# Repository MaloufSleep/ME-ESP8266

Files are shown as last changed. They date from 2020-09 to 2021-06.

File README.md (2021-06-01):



# ME-ESP8266
Malouf Electronics - ESP8266 Dev Board

The ultimate ESP8266 development board built by makers for makers.



[Malouf Electronics website](https://www.maloufelectronics.com)



## SPECIFICATIONS / FEATURES



* 16 MB Flash
* 5V Relay
* RS232 interface
* IR Receiver
* IR LED
* Terminal Block for Power & RS232
* Terminal Block for Relay
* Easily accessible GPIO
* Micro USB (power & programming)

## GETTING STARTED
1. Download Arduino IDE (https://www.arduino.cc/en/Main/Software)
2. Setup ESP8266 support for Arduino IDE:
* Start Arduino and open Preferences window.
* Enter https://arduino.esp8266.com/stable/package_esp8266com_index.json into the Additional Board Manager URLs field.
* Open Boards Manager from the Tools > Board menu and find esp8266 platform.
* Select the version you need from the drop-down box.
* Click the Install button.
* Don't forget to select your ESP8266 board from the Tools > Board menu after installation.
3. Select "Generic ESP8266 Module"
4. Pick the following from the Tools menu:
* Upload Speed: 115200
* CPU Frequency: 80MHz
* Crystal Frequency: 26MHz
* Flash Size: 16MB
* Flash Mode: DOUT
* Flash Frequency: 40MHz
* Port: (the serial port of your USB cable)
5. Paste the code below into a new sketch and upload to the board (In order to upload you may have to hold the boot button until esptool connects):

```
const int LED_RED = 5;

void setup() {
    pinMode(LED_RED, OUTPUT);     // setup red LED as output
}

void loop() {

    digitalWrite(LED_RED, LOW);   // turn the LED on
    delay(1000);                  // wait for a second

    digitalWrite(LED_RED, HIGH);  // turn the LED off
    delay(1000);                  // wait for a second

}
```

If all goes well the board will program and the red LED will start blinking.



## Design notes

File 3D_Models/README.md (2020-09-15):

The folders here contain 3d models of any ‘non-standard’ part, meaning the kicad libraries don’t contain them. Folders are named to match kicad’s naming convention so you can merge them with the global folders if you’d like (/Library/Application Support/kicad/modules/packages3d). This will allow you to use the same models between projects without having to change file paths. 

If you need/want any other 3d models for the project, please let me know and I’ll get them to you.

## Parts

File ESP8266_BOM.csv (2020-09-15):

Designator | Quantity | Value | LCSC Part # | Footprint | Notes
C1, | 1 | TAJB107K006RNJ | C16133 | Capacitor_Tantalum_SMD:CP_EIA-3528-15_AVX-H
C3, C16, C17, | 3 | CL21A106KAYNNNE | C15850 | Capacitor_SMD:C_0805_2012Metric
C4, C5, C13, C14, C15, C12, | 6 | CL10A105KB8NNNC | C15849 | Capacitor_SMD:C_0603_1608Metric
C6, | 1 | 0402CG2R7C500NT | C1561 | Capacitor_SMD:C_0402_1005Metric
C7, | 1 | 0603CG3R0C500NT | C46219 | Capacitor_SMD:C_0603_1608Metric
C8, C2, C11, C18, C19, | 5 | CC0603KRX7R9BB104 | C14663 | Capacitor_SMD:C_0603_1608Metric
C9, C10, | 2 | 0603CG6R8C500NT | C1679 | Capacitor_SMD:C_0603_1608Metric
D4, | 1 | SS14 | C2480 | Diode_SMD:DO-214AC
D5, | 1 | M7 | C95872 | Diode_SMD:DO-214AC
L1, | 1 | SDCL1005C4N3STDF | C52051 | Inductor_SMD:L_0402_1005Metric
L2, | 1 | LQG15HS2N2S02D | C86061 | Inductor_SMD:L_0402_1005Metric
Q2, Q3, Q6, Q1, | 4 | AO3400A | C20917 | Package_TO_SOT_SMD:SOT-23
Q4, Q5, | 2 | S8050_SMD | C2146 | Package_TO_SOT_SMD:SOT-23
R1, | 1 | 0603WAF2000T5E | C8218 | Resistor_SMD:R_0603_1608Metric
R2, R4, R5, R6, R7, R12, R13, R24, R25, R26, R20, | 11 | 0603WAF1002T5E | C25804 | Resistor_SMD:R_0603_1608Metric
R3, | 1 | 0603WAF1202T5E | C22790 | Resistor_SMD:R_0603_1608Metric
R8, R14, R23, R22, R21, R19, R15, R16, | 8 | 0603WAF4700T5E | C23179 | Resistor_SMD:R_0603_1608Metric
R9, R11, R10, | 3 | 0603WAF620JT5E | C23222 | Resistor_SMD:R_0603_1608Metric
R17, | 1 | 0805W8F2203T5E | C17556 | Resistor_SMD:R_0805_2012Metric
R18, | 1 | 0805W8F8202T5E | C17840 | Resistor_SMD:R_0805_2012Metric
SW1, SW2, | 2 | TS-1187A-B-A-B | C318884 | Button_Switch_SMD:TS-1187A-B-A-B
U1, | 1 | W25Q128JVSIQ | C97521 | Package_SO:SO-8_5.3x6.2mm_P1.27mm
U2, | 1 | ESP8266EX | C77967 | Package_DFN_QFN:QFN-32-1EP_5x5mm_P0.5mm_EP3.45x3.45mm_ThermalVias
U3, | 1 | MAX232ESE+T | C26860 | Package_SO:SOIC-16_3.9x9.9mm_P1.27mm
U4, | 1 | NCP1117-3.3_SOT223 | C26537 | Package_TO_SOT_SMD:SOT-223-3_TabPin2
U5, | 1 | CH340C | C84681 | Package_SO:SOIC-16_3.9x9.9mm_P1.27mm
X1, | 1 | X1E000021081900 | C91747 | Crystal:Crystal_SMD_3225-4Pin_3.2x2.5mm
D1 | 1 | QBL7SA60D |  | LED_3mm_Radial | substitution okay
D2 | 1 | QBL7IG60D |  | LED_3mm_Radial | substitution okay
D3 | 1 | TSHA4400 |  | LED_3mm_Radial | substitution okay
J1, | 1 | 282834-4 |  | TerminalBlock_TE-Connectivity:TerminalBlock_TE_282834-4_1x04_P2.54mm_Horizontal | substitution okay
J2, | 1 | 68000-113HLF |  | Connector_PinHeader_2.54mm:PinHeader_1x13_P2.54mm_Vertical | substitution okay
J3, | 1 | 10118193-0001LF |  | digikey-footprints:USB_Micro_B_Female_10118193-0001LF | substitution okay
J4, | 1 | 68000-102HLF |  | Connector_PinHeader_2.54mm:PinHeader_1x02_P2.54mm_Vertical | substitution okay
J5, | 1 | 284391-3 |  | TerminalBlock_TE-Connectivity:TE_284391-3 | substitution okay
K1, | 1 | G5LE-14 DC5 |  | Relay_THT:Relay_SPDT_Omron-G5LE-1 | substitution okay
U6, | 1 | VS1838B |  | OptoDevice:Vishay_MOLD-3Pin | substitution okay

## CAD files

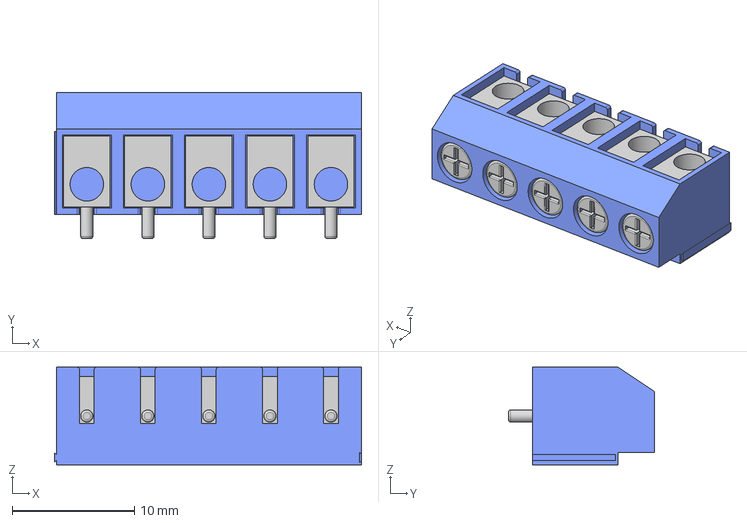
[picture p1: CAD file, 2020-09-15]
3D_Models/screw-terminal-block-5mm-2.snapshot.17/Screw Terminal Block 5mm Blue 5-way.step
25.1 x 12.0 x 8.00 mm

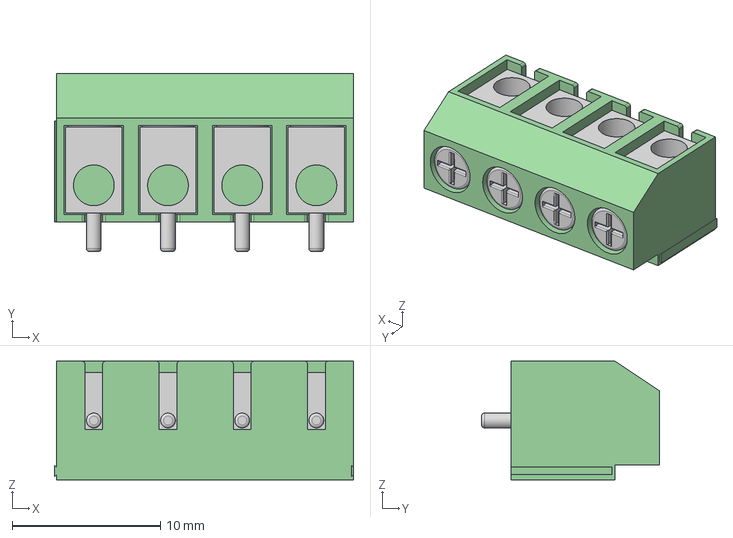
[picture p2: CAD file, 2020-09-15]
3D_Models/screw-terminal-block-5mm-2.snapshot.17/Screw Terminal Block 5mm 4-way.step
20.1 x 12.0 x 8.00 mm

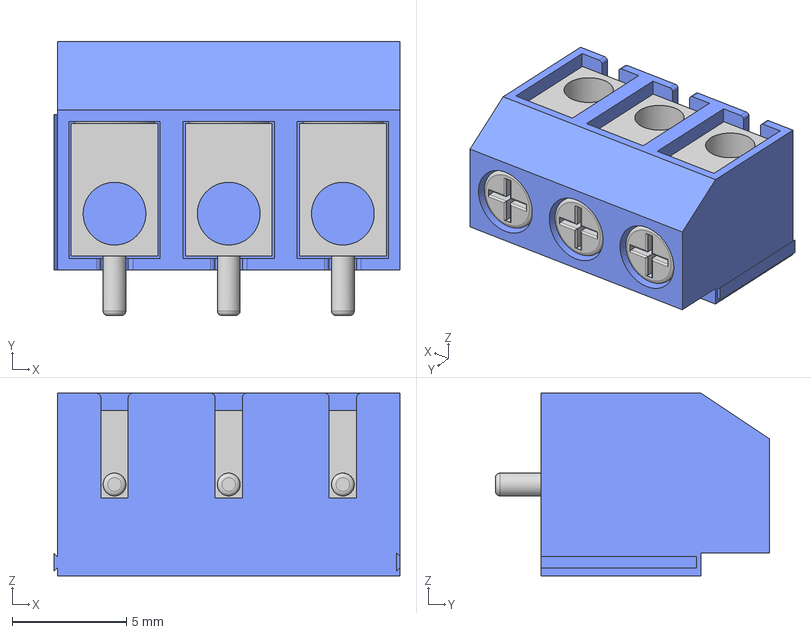
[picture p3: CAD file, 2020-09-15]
3D_Models/screw-terminal-block-5mm-2.snapshot.17/Screw Terminal Block 5mm Blue 3-way.step
15.2 x 12.0 x 8.00 mm

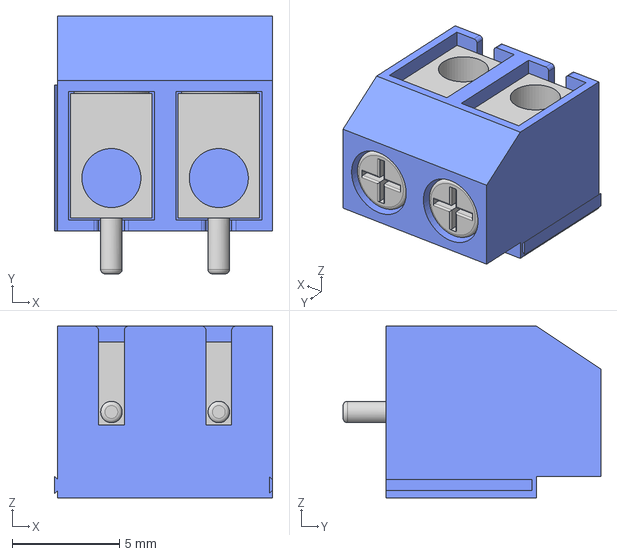
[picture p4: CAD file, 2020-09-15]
3D_Models/screw-terminal-block-5mm-2.snapshot.17/Screw Terminal Block 5mm Blue 2-way.step
10.2 x 12.0 x 8.00 mm

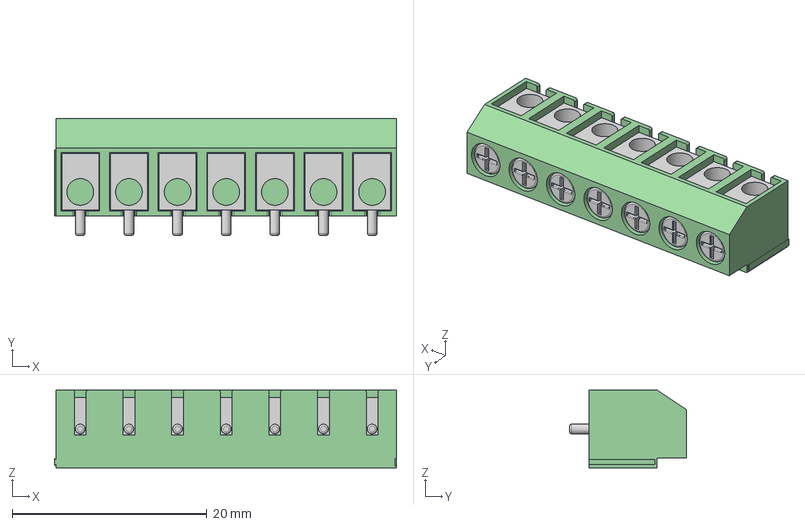
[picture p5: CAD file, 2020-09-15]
3D_Models/screw-terminal-block-5mm-2.snapshot.17/Screw Terminal Block 5mm 7-way.step
35.1 x 12.0 x 8.00 mm

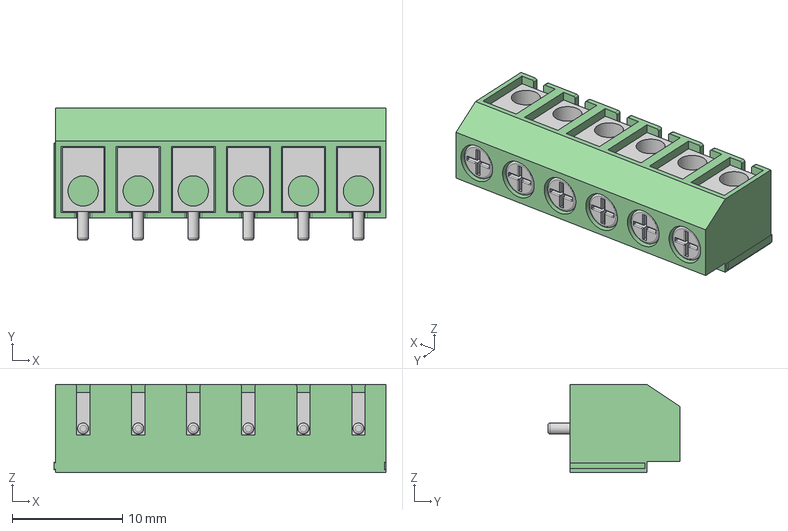
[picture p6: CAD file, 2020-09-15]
3D_Models/screw-terminal-block-5mm-2.snapshot.17/Screw Terminal Block 5mm 6-way.step
30.1 x 12.0 x 8.00 mm

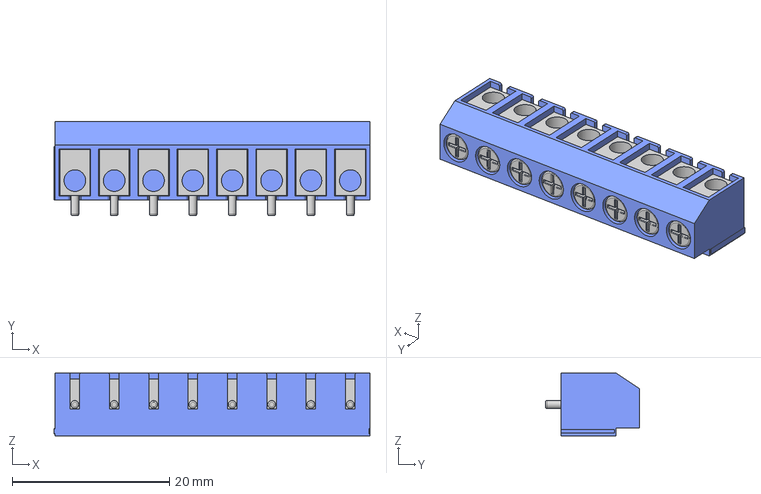
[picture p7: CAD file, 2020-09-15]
3D_Models/screw-terminal-block-5mm-2.snapshot.17/Screw Terminal Block 5mm Blue 8-way.step
40.1 x 12.0 x 8.00 mm

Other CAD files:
3D_Models/screw-terminal-block-5mm-2.snapshot.17/Screw Terminal Block 5mm Blue 7-way.step
3D_Models/screw-terminal-block-5mm-2.snapshot.17/Screw Terminal Block 5mm 8-way.step
3D_Models/screw-terminal-block-5mm-2.snapshot.17/Screw Terminal Block 5mm 5-way.step
3D_Models/screw-terminal-block-5mm-2.snapshot.17/Screw Terminal Block 5mm 2-way.step
3D_Models/screw-terminal-block-5mm-2.snapshot.17/Screw Terminal Block 5mm Blue 4-way.step
3D_Models/screw-terminal-block-5mm-2.snapshot.17/Screw Terminal Block 5mm Blue 6-way.step
3D_Models/screw-terminal-block-5mm-2.snapshot.17/Screw Terminal Block 5mm 3-way.step

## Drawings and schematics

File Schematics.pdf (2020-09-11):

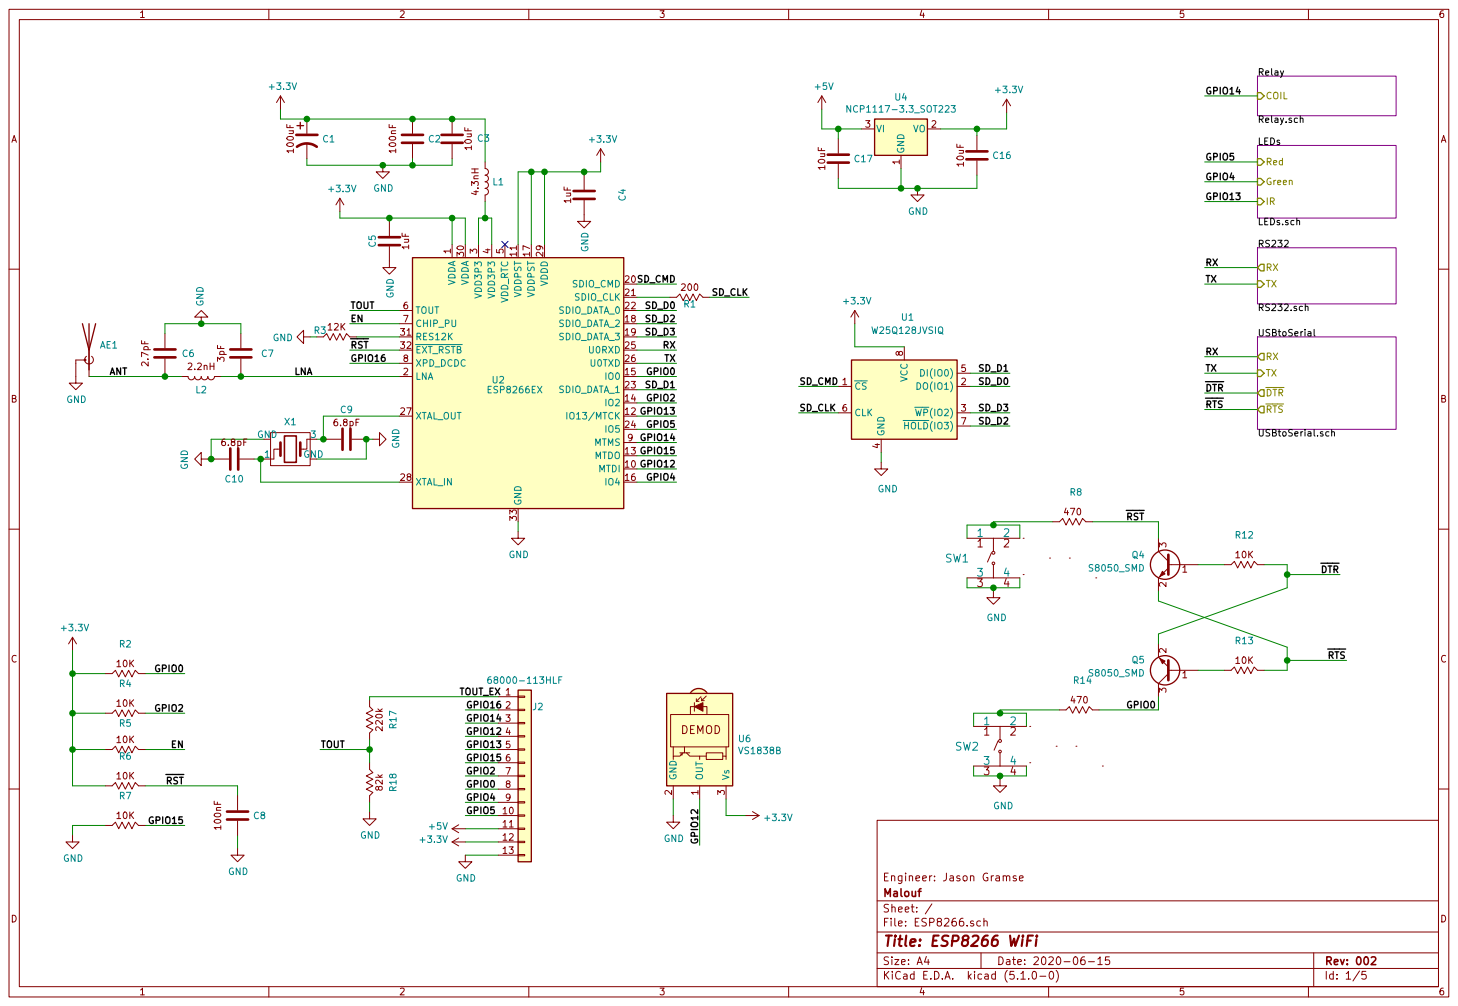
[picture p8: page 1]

Relay
LEDs LEDs.sch Red Green

5 TOUT 6 CHIP_PU 7 XPD_DCDC 8 MTMS 9 U2 ESP8266EX 1uF C4 C5 1uF GNDGND GND 4.3nH L1 +3.3V CS 1 DO(IO1) 2 WP(IO2) 3 GND

1 MTDI 10 VDDPST 11
Id: 1/5 Title: ESP8266 WiFi File: ESP8266.sch Sheet: / Malouf Engineer: Jason Gramse VDDA

USBtoSerial USBtoSerial.sch RX

4 DI(IO0) 5 CLK 6 HOLD(IO3) 7 VCC

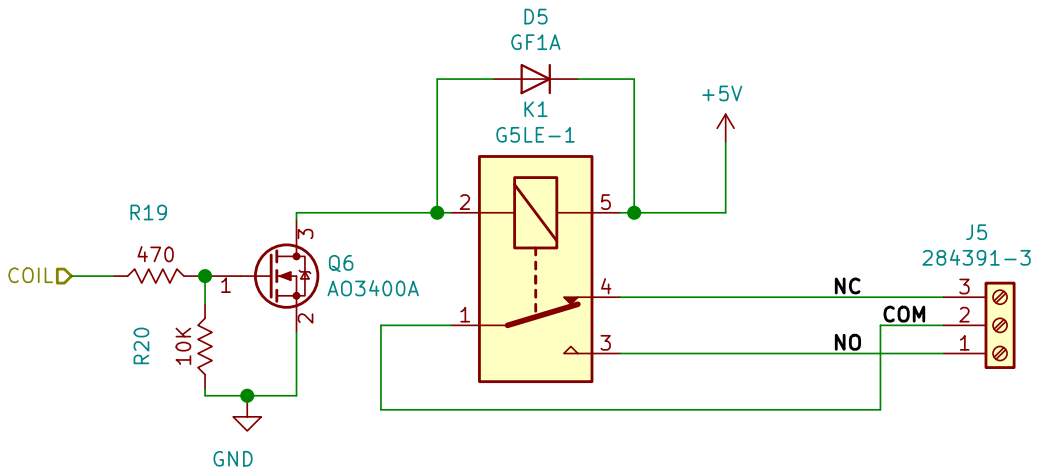
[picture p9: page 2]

Sheet: /Relay/ Malouf Engineer: Jason Gramse

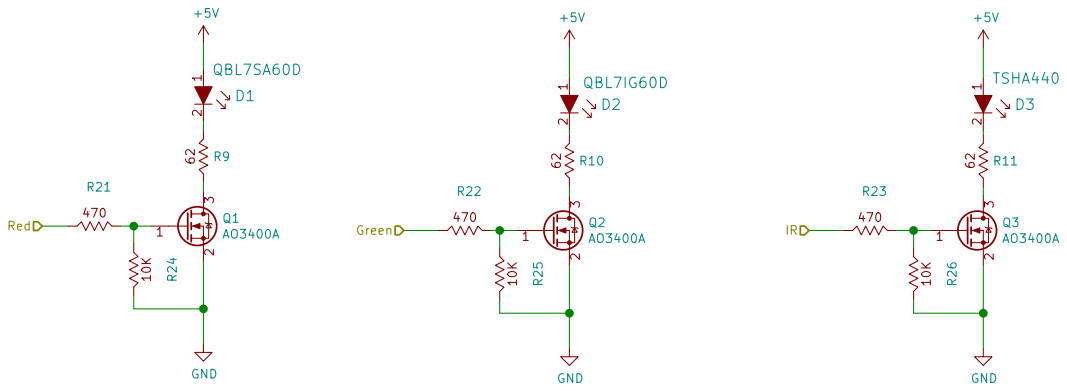
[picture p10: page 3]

Id: 3/5 Title: ESP8266 WiFi File: LEDs.sch Sheet: /LEDs/ Malouf Engineer: Jason Gramse

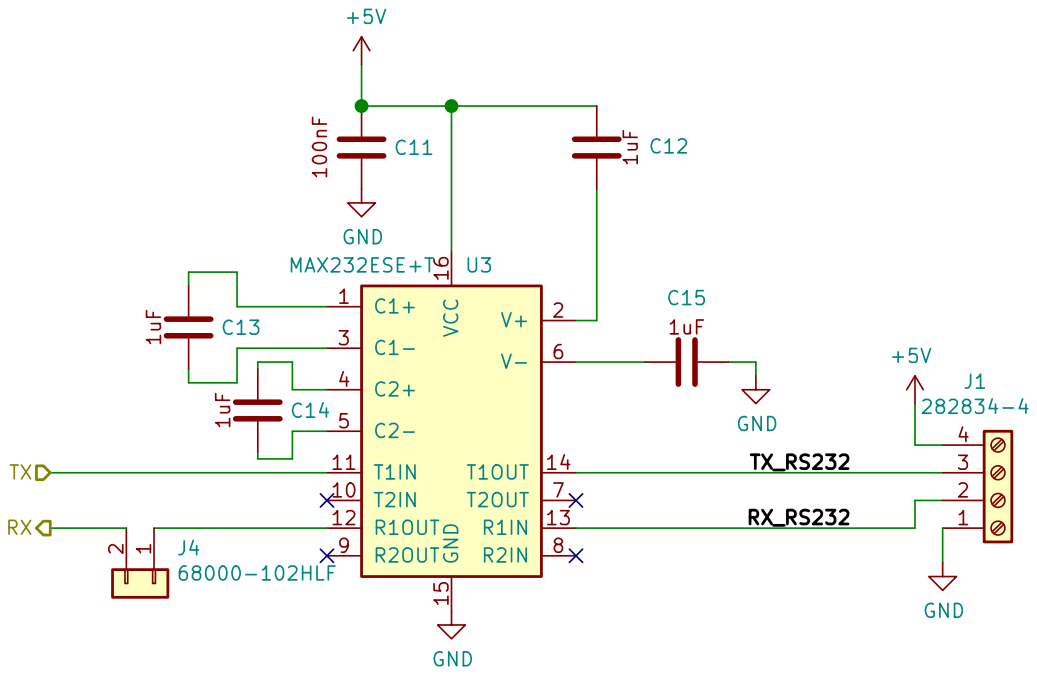
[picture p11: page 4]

Id: 4/5 Title: ESP8266 WiFi File: RS232.sch Sheet: /RS232/ Malouf Engineer: Jason Gramse

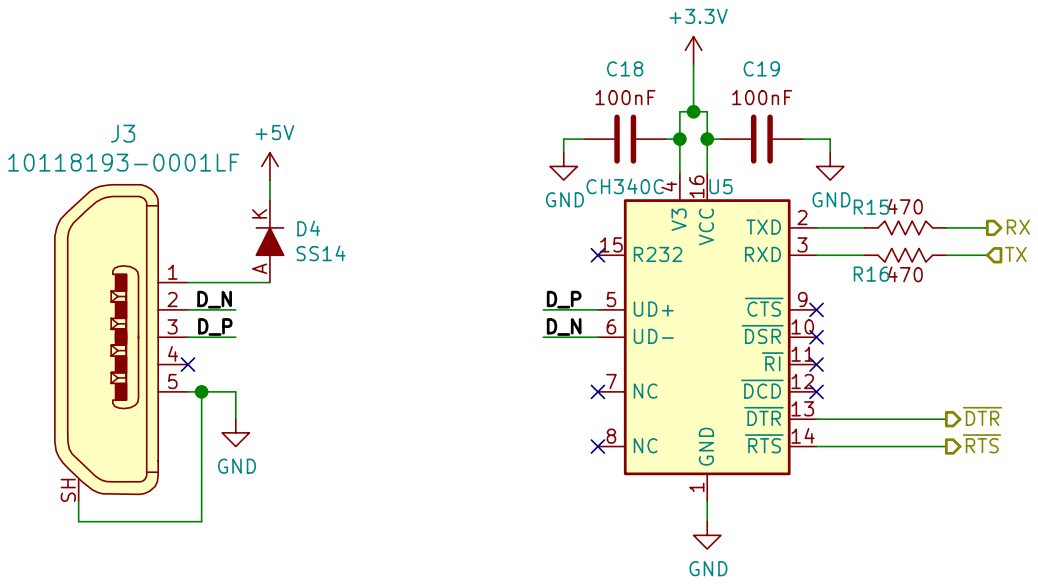
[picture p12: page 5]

4 UD+ 5 UD- 6 NC 7 NC 8 CTS 9 CH340C U5 +3.3V GND GNDR15470 R16470 GND
100nF C19 GND

1 DSR 10 RI 11 DCD 12 DTR 13 RTS 14 R232 15 VCC 16 TXD 2 RXD 3 V3

Id: 5/5 Title: ESP8266 WiFi File: USBtoSerial.sch Sheet: /USBtoSerial/ Malouf Engineer: Jason Gramse

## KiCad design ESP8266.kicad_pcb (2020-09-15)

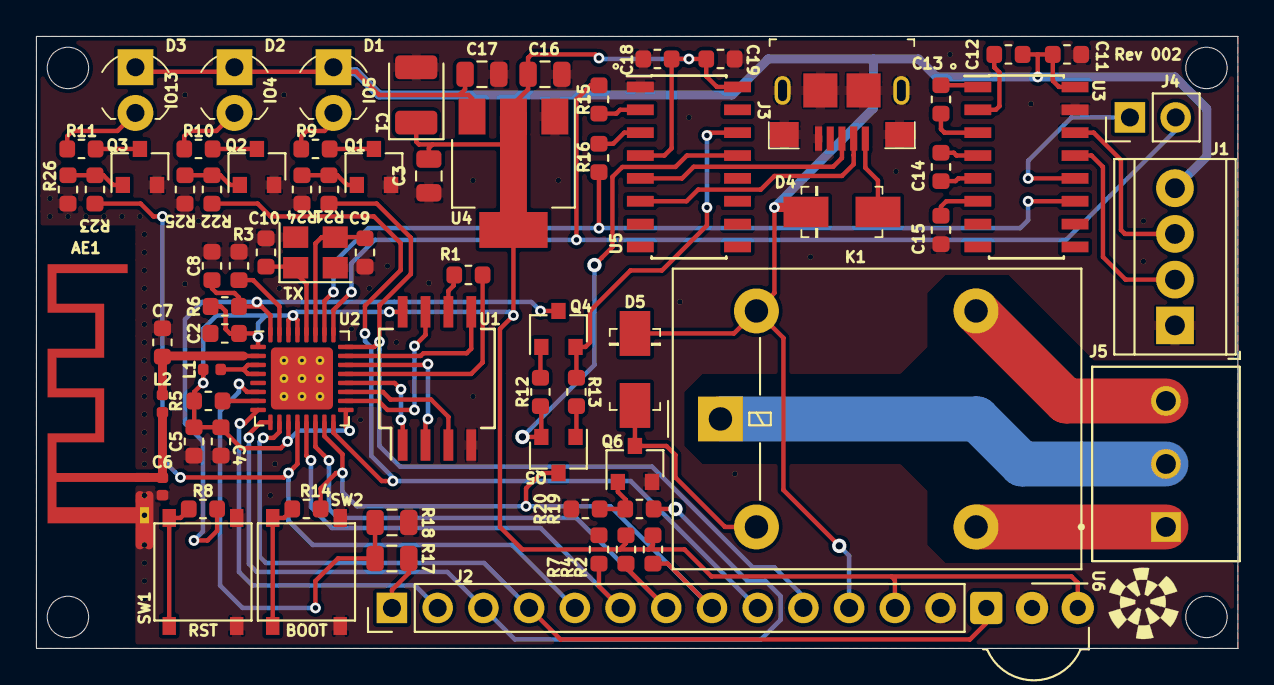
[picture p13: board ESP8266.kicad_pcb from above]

Board: 2 copper layers, 66.8 x 34.0 mm, 74 parts (0 on the bottom side), 65 nets.

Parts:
AE1: Antenna_Shield; Texas_SWRA117D_2.4GHz_Right
C1: TAJB107K006RNJ; CP_EIA-3528-15_AVX-H
C2, C8, C11, C18, C19: CC0603KRX7R9BB104; C_0603_1608Metric
C3, C16, C17: CL21A106KAYNNNE; C_0805_2012Metric
C4, C5, C12, C13, C14, C15: CL10A105KB8NNNC; C_0603_1608Metric
C6: 0402CG2R7C500NT; C_0402_1005Metric
C7: 0603CG3R0C500NT; C_0603_1608Metric
C9, C10: 0603CG6R8C500NT; C_0603_1608Metric
D1: QBL7SA60D; LED_3mm_Radial
D2: QBL7IG60D; LED_3mm_Radial
D3: TSHA440; LED_3mm_Radial
D4: SS14; DO-214AC
D5: GF1A; DO-214AC
J1: 282834-4; TerminalBlock_TE_282834-4_1x04_P2.54mm_Horizontal
J2: 68000-113HLF; PinHeader_1x13_P2.54mm_Vertical
J3: 10118193-0001LF; USB_Micro_B_Female_10118193-0001LF
J4: 68000-102HLF; PinHeader_1x02_P2.54mm_Vertical
J5: 284391-3; TE_284391-3
K1: G5LE-1; Relay_SPDT_Omron-G5LE-1
L1: SDCL1005C4N3STDF; L_0402_1005Metric
L2: LQG15HS2N2S02D; L_0402_1005Metric
Q1, Q2, Q3, Q6: AO3400A; SOT-23
Q4, Q5: S8050_SMD; SOT-23
R1: 0603WAF2000T5E; R_0603_1608Metric
R2, R4, R5, R6, R7, R12, R13, R20, R24, R25, R26: 0603WAF1002T5E; R_0603_1608Metric
R3: 0603WAF1202T5E; R_0603_1608Metric
R8, R14, R15, R16, R19, R21, R22, R23: 0603WAF4700T5E; R_0603_1608Metric
R9, R10, R11: 0603WAF620JT5E; R_0603_1608Metric
R17: 0805W8F2203T5E; R_0805_2012Metric
R18: 0805W8F8202T5E; R_0805_2012Metric
SW1, SW2: TS-1187A-B-A-B
U1: W25Q128JVSIQ; SO-8_5.3x6.2mm_P1.27mm
U2: ESP8266EX; QFN-32-1EP_5x5mm_P0.5mm_EP3.45x3.45mm_ThermalVias
U3: MAX232ESE+T; SOIC-16_3.9x9.9mm_P1.27mm
U4: NCP1117-3.3_SOT223; SOT-223-3_TabPin2
U5: CH340C; SOIC-16_3.9x9.9mm_P1.27mm
U6: VS1838B; Vishay_MOLD-3Pin
X1: X1E000021081900; Crystal_SMD_3225-4Pin_3.2x2.5mm

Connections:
+3V3: C1.1, C2.1, C3.2, C4.1, C5.2, C16.1, C18.1, C19.2, J2.12, L1.1, R2.2, R4.2, R5.2, R6.2, U1.8, U2.1, U2.11, U2.17, U2.29, U2.30, U4.2, U5.4, U5.16, U6.3
+5V: C11.1, C12.2, C17.1, D1.1, D2.1, D3.1, D4.K, D5.K, J1.4, J2.11, K1.5, U3.16, U4.3
/ANT: AE1.1, C6.2, L2.2
/EN: R5.1, U2.7
/GPIO0: J2.8, Q5.3, R2.1, R14.1, U2.15
/GPIO2: J2.7, R4.1, U2.14
/GPIO4: J2.9, R22.2, U2.16
/GPIO5: J2.10, R21.2, U2.24
/GPIO12: J2.4, U2.10, U6.1
/GPIO13: J2.5, R23.2, U2.12
/GPIO14: J2.3, R19.1, U2.9
/GPIO15: J2.6, R7.1, U2.13
/GPIO16: J2.2, U2.8
/LNA: C7.2, L2.1, U2.2
/RS232/RX_RS232: J1.2, U3.13
/RS232/TX_RS232: J1.3, U3.14
/RX: J4.2, R15.1, U2.25
/Relay/COM: J5.2, K1.1
/Relay/NC: J5.3, K1.4
/Relay/NO: J5.1, K1.3
/SD_CLK: R1.1, U1.6
/SD_CMD: U1.1, U2.20
/SD_D0: U1.2, U2.22
/SD_D1: U1.5, U2.23
/SD_D2: U1.7, U2.18
/SD_D3: U1.3, U2.19
/TOUT: R17.1, R18.2, U2.6
/TOUT_EX: J2.1, R17.2
/TX: R16.1, U2.26, U3.11
/USBtoSerial/D_N: J3.2, U5.6
/USBtoSerial/D_P: J3.3, U5.5
/~DTR: Q5.2, R12.1, U5.13
/~RST: C8.1, Q4.3, R6.1, R8.1, U2.32
/~RTS: Q4.2, R13.1, U5.14
GND: AE1.2, C1.2, C2.2, C3.1, C4.2, C5.1, C6.1, C7.1, C8.2, C9.1, C10.2, C11.2, C15.1, C16.2, C17.2, C18.2, C19.1, J1.1, J2.13, J3.5, J3.SH, Q1.2, Q2.2, Q3.2, Q6.2, R3.2, R7.2, R18.1, R20.1, R24.1, R25.1, R26.1, SW1.3, SW1.4, SW2.3, SW2.4, U1.4, U2.33, U3.15, U4.1, U5.1, U6.2, X1.2, X1.4
unnamed: C9.2, U2.27, X1.3
unnamed: C10.1, U2.28, X1.1
unnamed: C12.1, U3.2
unnamed: C13.1, U3.1
unnamed: C13.2, U3.3
unnamed: C14.1, U3.4
unnamed: C14.2, U3.5
unnamed: C15.2, U3.6
unnamed: D1.2, R9.1
unnamed: D2.2, R10.1
unnamed: D3.2, R11.1
unnamed: D4.A, J3.1
unnamed: D5.A, K1.2, Q6.3
unnamed: J4.1, U3.12
unnamed: L1.2, U2.3, U2.4
unnamed: Q1.1, R21.1, R24.2
unnamed: Q1.3, R9.2
unnamed: Q2.1, R22.1, R25.2
unnamed: Q2.3, R10.2
unnamed: Q3.1, R23.1, R26.2
unnamed: Q3.3, R11.2
unnamed: Q4.1, R12.2
unnamed: Q5.1, R13.2
unnamed: Q6.1, R19.2, R20.2
unnamed: R1.2, U2.21
unnamed: R3.1, U2.31
unnamed: R8.2, SW1.1, SW1.2
unnamed: R14.2, SW2.1, SW2.2
unnamed: R15.2, U5.2
unnamed: R16.2, U5.3

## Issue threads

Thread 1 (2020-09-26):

Wrong data sheets for connectors

busheezy, 2020-09-26:
ME-ESP8266/Datasheets/Connectors/284391-3.pdf shows 284391-2's datasheet.
ME-ESP8266/Datasheets/Connectors/284391-4.pdf shows 284391-3's datasheet.

Thanks

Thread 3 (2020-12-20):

for Rev 2 - eliminate the MOSFET gate voltage dividers

Tech-TX, 2020-12-20:
Swap those 10K pull-downs from the _gate_ of the MOSFETs (4 places) to the _GPIO side_ of the 470 ohm resistors for slightly improved Rds(on).  You've created a voltage divider, reducing the gate drive voltage from 3.3V to 3.152V.  You get much the same protection at power-up without the loss of drive voltage.

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

gramsejrm, 2021-01-28:
Thanks for the tip! I'll add that fix in the next revision.

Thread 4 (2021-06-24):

MicroPython support?

PinkFreud, 2021-06-24:
Despite claimed support on www.maloufelectronics.com/story for python, I can't figure out how to convince MicroPython to load on this board.

Following the directions for generic ESP8266 support on http://docs.micropython.org/en/v1.16/esp8266/tutorial/intro.html, coupled with information from the main README in this repo, I've tried flashing both MicroPython 1.16 and 1.15 with the following options:
`$ esptool.py --port /dev/ttyUSB0 --baud 115200 write_flash --flash_size=detect -fm dout 0 esp8266-20210618-v1.16.bin`

I only get garbage on the serial port - I've tried a variety of baud rates, including 115200 (default for the python REPL), 74880 (default for the python bootloader), 230400, 460800 - all I get is garbage at all of these.  The fact that I'm not seeing any boot messages at 74880 further tells me that this board is completely failing to load MicroPython from the flashed image.

Has python support been tested on this board?  If so, is there some trick to getting a flash to succeed that I haven't figured out yet?

PinkFreud, 2021-06-24:
> I only get garbage on the serial port - I've tried a variety of baud rates, including 115200 (default for the python REPL), 74880 (default for the python bootloader)

Never mind on this part - it looks like screen doesn't work with 74880 baud.  I've changed to miniterm.py, and can now see the boot messages.

The rest of this issue still stands - MicroPython is failing to boot.  However, I now have more information to go on from the bootloader:
`ets Jan  8 2013,rst cause:2, boot mode:(3,1)

load 0x40100000, len 30736, room 16
tail 0
chksum 0x47
load 0x3ffe8000, len 996, room 8
tail 12
chksum 0x99
ho 0 tail 12 room 4
load 0x3ffe83f0, len 1064, room 12
tail 12
chksum 0xaa
csum 0xaa
rf_cal[0] !=0x05,is 0xFF
`

PinkFreud, 2021-06-24:
And closing.  This is a problem with micropython, documented in issue 2335.

https://github.com/micropython/micropython/issues/2335#issuecomment-520210822 has the fix.  I've been able to confirm that building the ESP sdk and building micropython via the sdk allows micropython to see the full 16MB flash.

fellowgeek, 2021-06-24:
Awesome, looks like you found the solution before I had a chance to dig into this.

Thanks :)

PinkFreud, 2021-06-24:
NP!  Thank you and your team for the board!

Closed 2021-06-24.
